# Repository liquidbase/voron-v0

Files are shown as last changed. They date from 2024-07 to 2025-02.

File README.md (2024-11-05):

# voron v0
Config repo for voron v0 to save the configuration and monitor changes made.

# Buildlog
26.07.2024
- Fixing Wiring
- Removed Display
- Removed BTT Pi1

27.07.2024
- Added Raspberry Pi 4B with MainsailOS
- 1st Startup
- Install updates for MainsailOS
- Upload first config
- Added main values for motors
- Added main vaules for thermistors
- Fixed macros
- Adjusted bed direction
- Adjusted StallGuard
- PID-Tuning für bed and nozzle

29.07.2024
- Added Display
- Added KlipperScreen

30.07.2024
- Added Shaketune
- Added Input Shaper LIS2DW
- Added frequencies
- Adjust frequencies

04.08.2024
- Disabled LIS2DW
- Layout Adjustments
- Configure Crowsnest
- Configure Neopixel

08.08.2024
- Added macro to control chamber led
- Better names

09.08.2024
- Adjust wait-time before print start
- Adjust value
- Added excluded_objects and adjusted run_current for X & Y
- Adjust Z-Endstop-Position
- Change invert on X & Y
- Added v0.2 CAD-File to .gitignore

13.08.2024
- Renamed comment
- Revert neopixel changes
- Adjusted neopixel color
- Adjusted position_endstop and max_temp

14.08.2024
- Enabled Line_Purge, Voron_Purge & Smart_Park
- Added KAMP for automatic Update

15.08.2024
- Changed chain_count for Neopixel
- Added better position after homing
- Added timelapse

14.09.2024
- Update temperatur for extruder and extrude distance
- Removed wait time and changed retract on print end

22.10.2024
- Moved Config folder to new folder Config_SKR-Pico
- Added config folder Config_Manta-M5P
- Added printer.cfg for Manta M5P after MCU change
- Removed uart_address

26.10.2024
- Added fan configuration
- Fixed neopixel pin

27.10.2024
- Added chamber thermistor

04.11.2024
- Fixed printer-section
- ReEnabled Sensorless homing

05.11.2024
- Added temperature sensors for mcu and host
- Added stepper config
- Fixed extruder

# Filelog
26.07.2024
- Added RPi_or_BTT-Pico_Mount.STL
- Added Images
- Added Image for MainsailOS to install
- Added display_mount.stl
- Added [a]_display_cover_hex_logo_x1.stl

27.07.2024
- Added rear_panel.3mf
- Added default printer.cfg for BTT SKR Pico

29.07.2024
- Added printfiles for handles
- Added new pictures
- Added KlipperScreen
- Added MFNano

30.07.2024
- Added ADXL Mount to printfiles

04.08.2024
- Removed MFNano
- Added Thermistormount in Chamber V0.2_NTC_10k_B3950_Mount.stl
- Added crowsnest.conf

06.08.2024
- Added waveshare-43-inch-display-mount-for-the-voron-v01-model_files

07.08.2024
- Added printfiles for LED-brackets, bottom hinge and Cam mount

14.08.2024
- Added moonraker.conf
- Added KAMP_Settings.cfg

15.08.2024
- Added diffuser print files
- Added print file for Front_Top_Right_Hinge_x1.stl

08.09.2024
- Added print files for Endstops

14.09.2024
- Added print files for 1515 end caps
- Added print files for Dragon Burner v8 with Orbiter v2
- Added print files for Dragon Burner v8 with Sherpa Mini

22.10.2024
- Added additional printfiles

26.10.2024
- Added printfiles for endstops

27.10.2024
- Added printfile for upper rear filament sensor

05.11.2024
- Added printfiles for foot corner
- Added printfiles for skirts

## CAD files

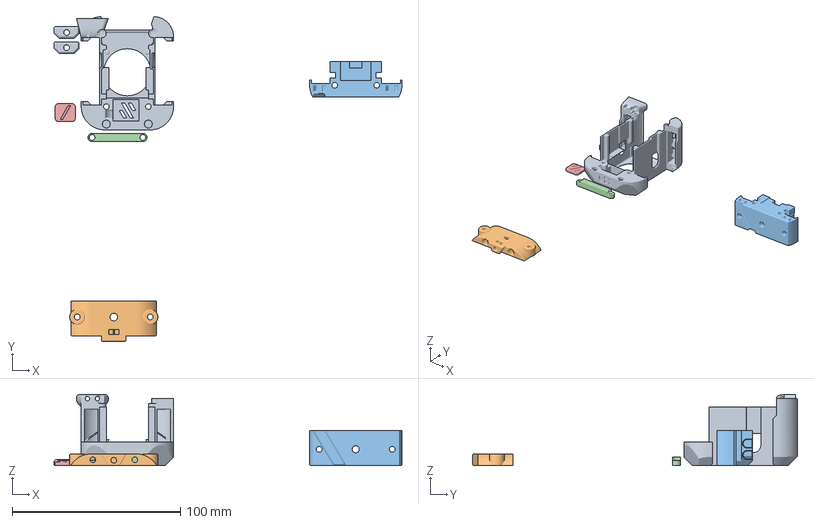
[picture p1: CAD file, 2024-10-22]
Printfiles/Dragon_Burner_v8_Sherpa_Mini/dragon_burner_v8.3mf
207.1 x 193.3 x 42.4 mm
Cowl_ZeroClick.stl
Sherpa_Mini_Mount.stl
Bambu_Mount.stl
Brace_Straight.stl
[c]_Voron_Diffuser.stl

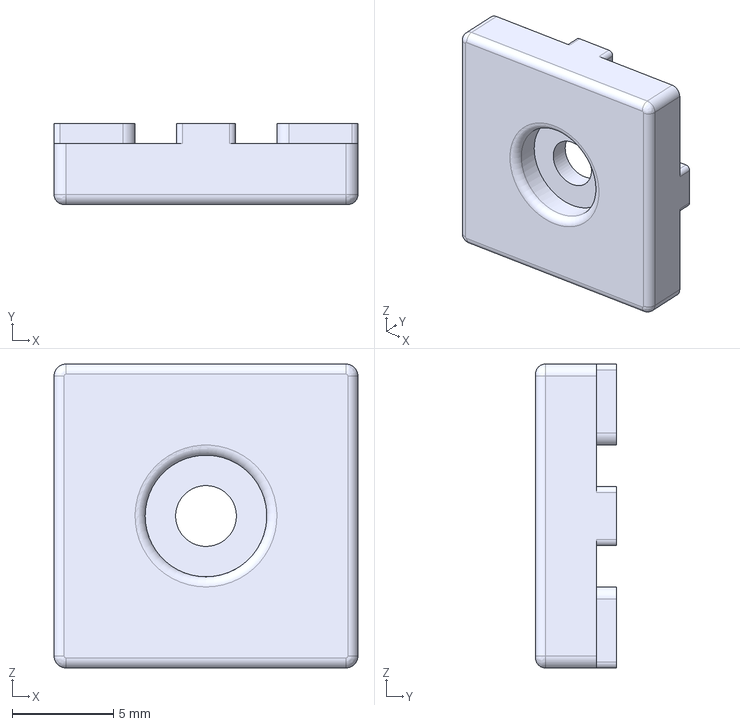
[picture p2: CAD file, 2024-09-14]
Printfiles/Endstop Case/1515 End Cap.step
15.0 x 4.00 x 15.0 mm

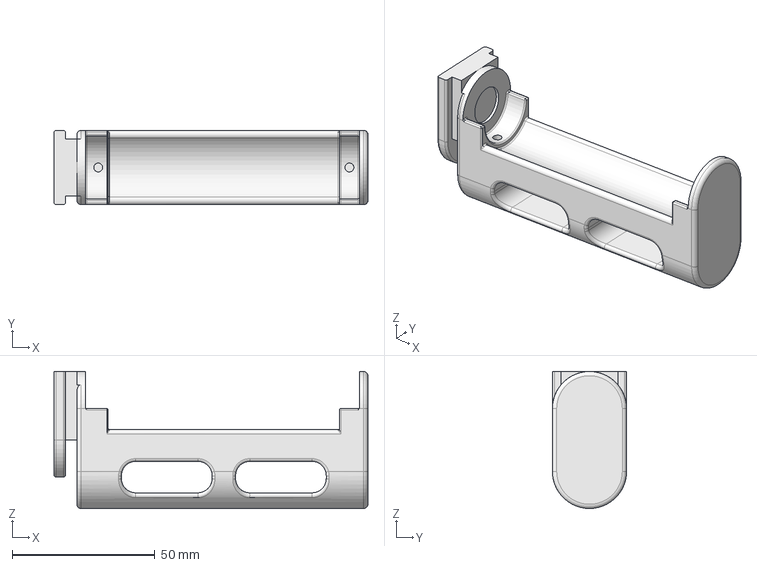
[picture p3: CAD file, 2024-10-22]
Printfiles/Filler 66mm Remix - 5335512/files/FillerBaseSource-66mm_mag.step
110.0 x 26.0 x 48.0 mm

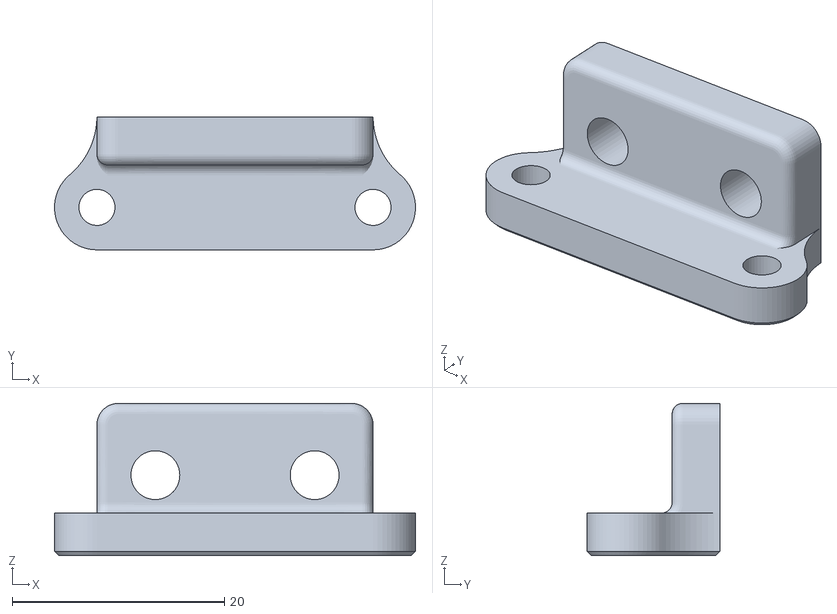
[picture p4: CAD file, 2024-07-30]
Printfiles/Mini Afterburner ADXL345 Mount by Andre/STL/MiniAB_ADXL345_Mount.stl
34.0 x 12.5 x 14.3

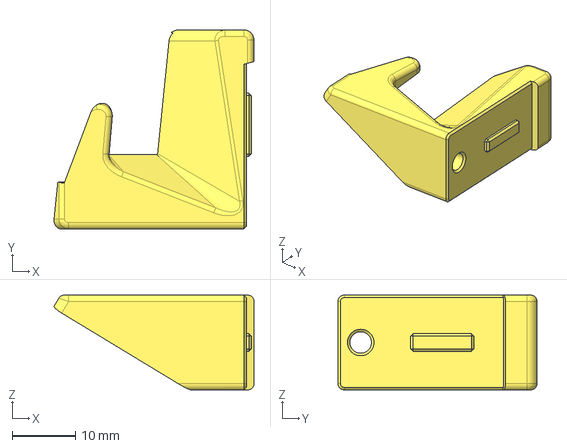
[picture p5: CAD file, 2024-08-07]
Printfiles/Raspberry Pi Camera Mount by johanncc/CAD/Raspberry_Pi_Camera_Mount.step
31.6 x 31.5 x 15.0 mm

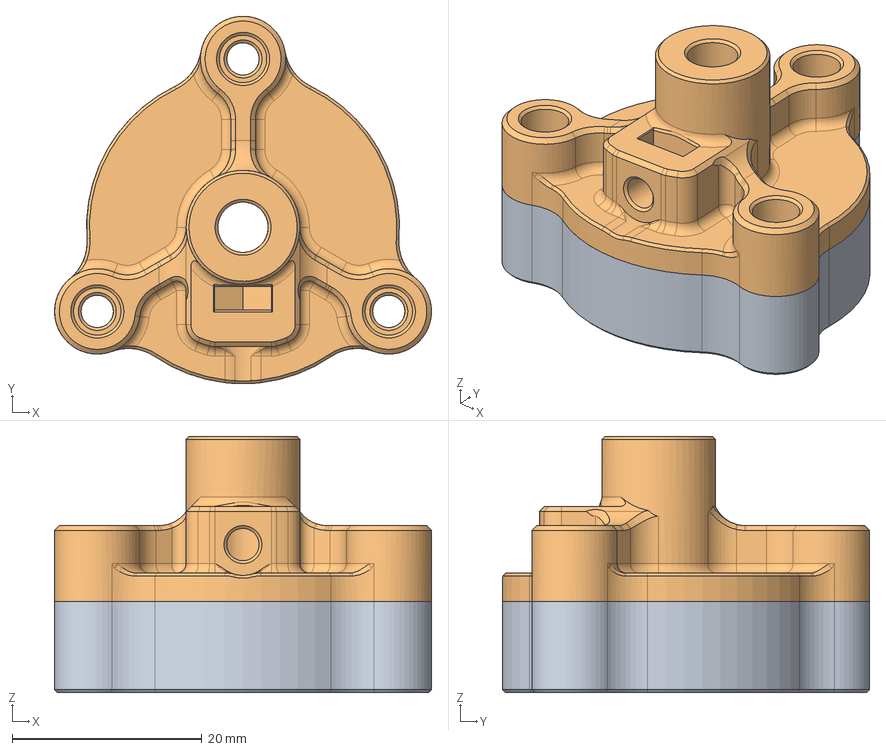
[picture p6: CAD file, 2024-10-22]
Printfiles/Sherpa_Mini-Extruder/Assembly_Tools/Shaft_Grinding_Tool/shaft_block v4.step
39.8 x 38.8 x 27.0 mm
bottom
top

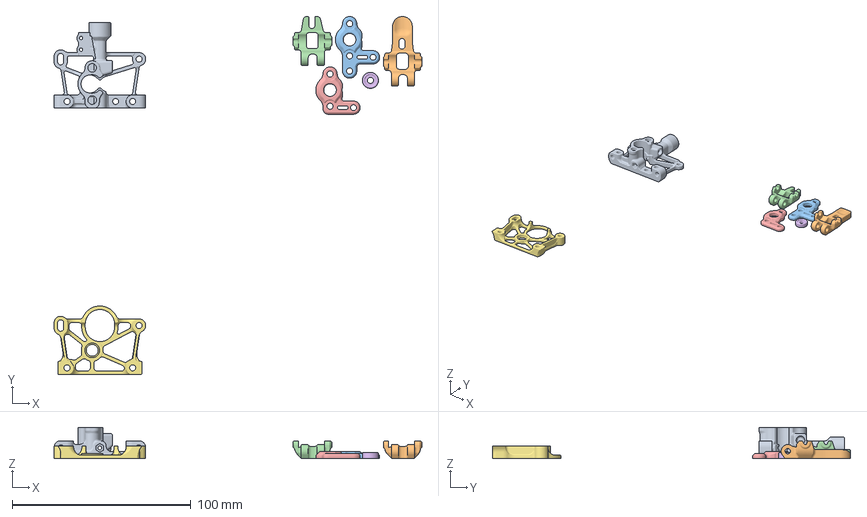
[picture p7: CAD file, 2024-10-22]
Printfiles/Sherpa_Mini-Extruder/housing_sherpa_mini_a3_r16(FDM)(FilamentSensor)(ECAS04).3mf
205.6 x 200.1 x 17.5 mm
housing_core_std^housing_sherpa_mini_a3_r16(FDM)(FilamentSensor)(ECAS04)
[a]_idler_arm_long_x1_rev16a.STL
[a]_housing_front_k_x1_rev15.STL
[a]_idler_arm_short_x1_rev16a.STL
[a]_housing_front_x1_rev15.STL
[a]_bondtech_thumbscrew_spacer_x1_rev1.STL
housing_rear_x1_rev17.STL

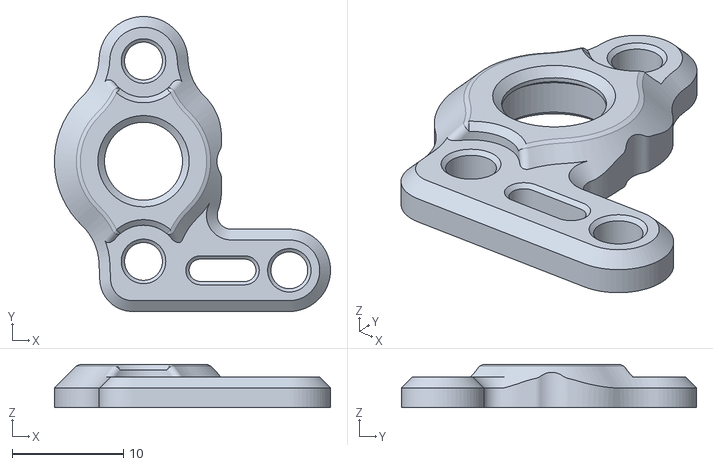
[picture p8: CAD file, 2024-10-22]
Printfiles/Sherpa_Mini-Extruder/STLs/[a]_housing_front_x1_rev15.STL
24.8 x 26.5 x 3.90

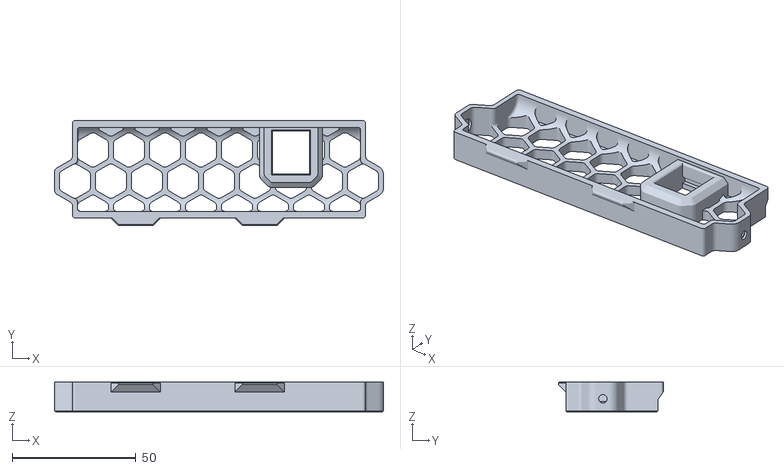
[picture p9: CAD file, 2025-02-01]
Printfiles/v0.2 Keystone Rear Skirt.stl
132.8 x 42.5 x 12.0

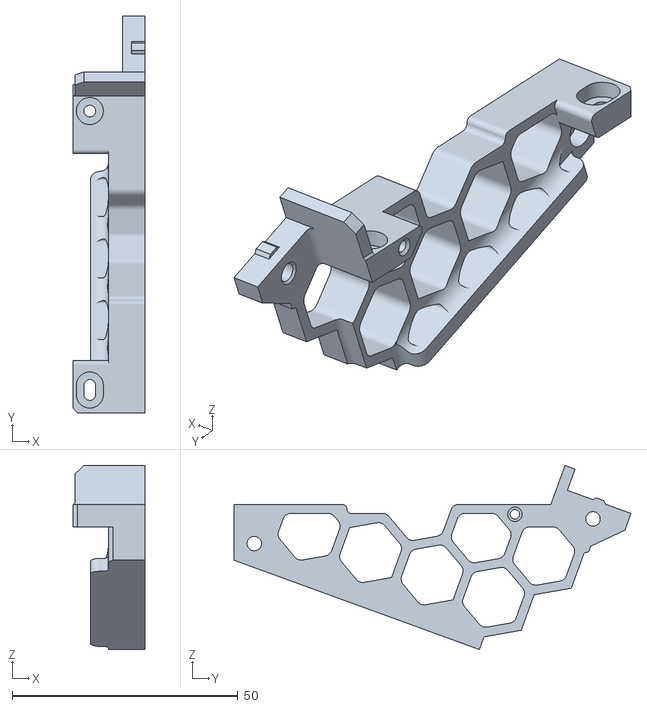
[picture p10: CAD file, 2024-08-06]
Printfiles/waveshare-43-inch-display-mount-for-the-voron-v01-model_files/mount_left.stl
15.9 x 88.0 x 40.8

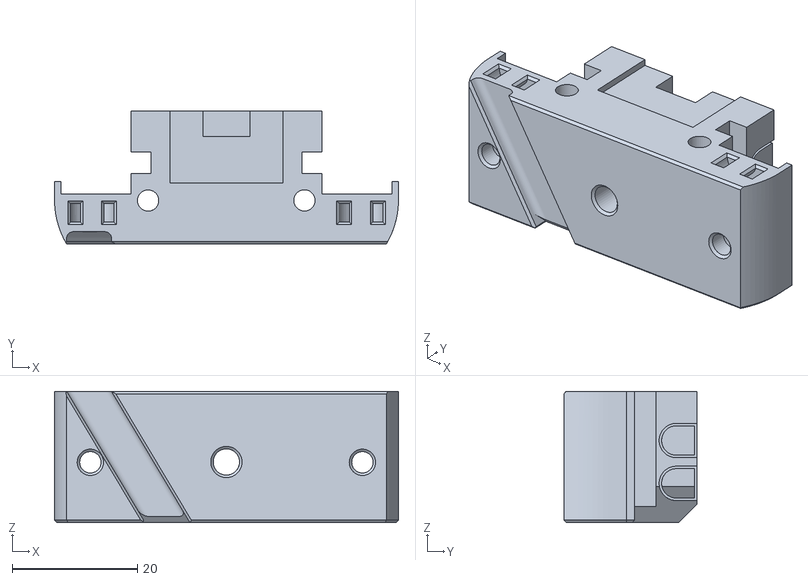
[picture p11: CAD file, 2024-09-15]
Printfiles/Dragon_Burner_v8_Sherpa_Mini/Bambu_Mount.stl
55.0 x 21.3 x 21.0

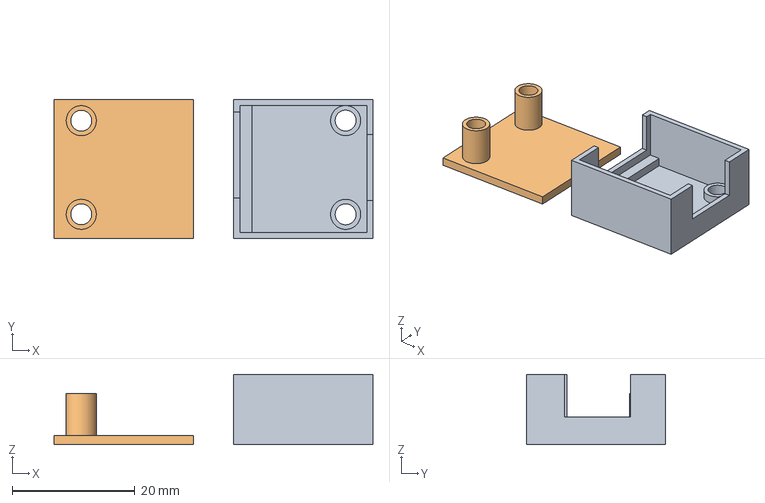
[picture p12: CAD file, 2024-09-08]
Printfiles/Endstop Case/Endstop Case v1.step
51.9 x 22.6 x 11.4 mm

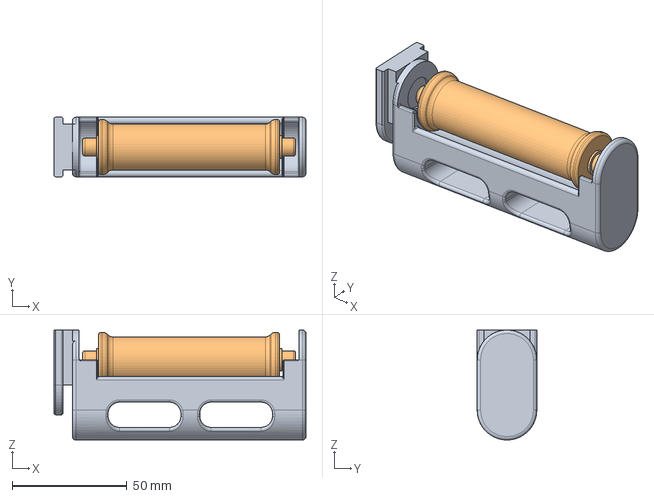
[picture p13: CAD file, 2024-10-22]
Printfiles/Filler 66mm Remix - 5335512/files/Filler-66mm.FCStd
110.0 x 26.0 x 48.0 mm
FillerBaseSource-66
FillerRollerSource-66

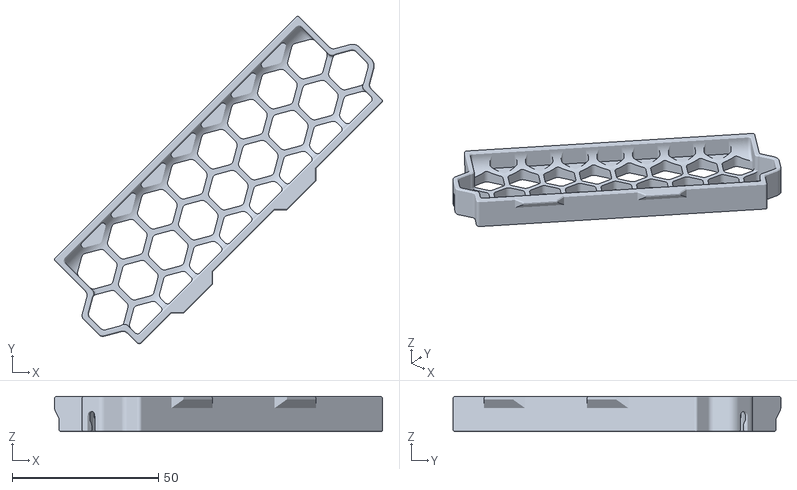
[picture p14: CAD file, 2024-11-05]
Printfiles/Rear_Skirt_x1.STL
112.3 x 112.1 x 12.0

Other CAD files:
Printfiles/Sherpa_Mini-Extruder/Assembly_Tools/Shaft_Grinding_Tool/bottom.stl
Printfiles/Sherpa_Mini-Extruder/STLs/housing_rear_x1_rev17.STL
Printfiles/Sherpa_Mini-Extruder/STLs/optional_parts/[a]_housing_front_k_x1_rev15.STL
Printfiles/1515 End Cap with Y Endstop for Voron V0.stl
Printfiles/1515_Hygrometer_mount.stl
Printfiles/Brackets_1515_x2.stl
Printfiles/Door_Latch_x2.STL
Printfiles/Dragon_Burner_v8_Sherpa_Mini/Brace_Straight.stl
Printfiles/Dragon_Burner_v8_Sherpa_Mini/Cowl_ZeroClick.stl
Printfiles/Dragon_Burner_v8_Sherpa_Mini/Sherpa_Mini_Mount.stl
Printfiles/Dragon_Burner_v8_Sherpa_Mini/[c]_Voron_Diffuser.stl
Printfiles/Endstop Case/1515 End Cap.stl
Printfiles/Endstop Case/1515 Endcap with Endstop Case v14.f3z
Printfiles/Endstop Case/1515 Endcap with Endstop Case v14.step
Printfiles/Endstop Case/1515 Endcap with Endstop Case v14.stl
Printfiles/Endstop Case/Endstop Case v1.f3d
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

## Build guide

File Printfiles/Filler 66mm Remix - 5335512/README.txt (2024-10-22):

Filler 66mm Remix by grzeegorzn on Thingiverse: https://www.thingiverse.com/thing:5335512

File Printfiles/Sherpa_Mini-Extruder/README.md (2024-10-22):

## Sherpa Mini - Release 2:

This release adds support for Bondtech's RIDGA v2 in addition to numerous tweaks and updates to make the extruder easier to work on and more reliable than ever. 

## Changelog

+ Bondtech RIDGA v2 compatibility (R2 RC1 and newer)
+ Bondtech insert support
+ Stronger and stiffer idler arm
+ Increased clearance between idler arm and core
+ Minor fixes and adjustments in preparation for upcoming upgrades

+ Core housing and rear housing need to be reprinted if upgrading from Release 1
+ Updated idler arms are backwards compatible with Release 1 and Release 2 RC1

## FAQ
For Material Requirements, Print Settings and How to Interpret the file naming structure, please see: "Print_Settings_and_File_Key.txt"

The BOM and Sourcing Guide for this product can be found here: https://docs.google.com/spreadsheets/d/1O3eyVuQ6M4F03MJSDs4Z71_XyNjXL5HFTZr1jsaAtRc/edit?usp=sharing

## Product Info
This is the Sherpa Mini Extruder, a ground up design developed by Anlin and the team at Annex Engineering. It's a dual geared hobbed filament extruder designed for use with any printer. It features a gear driven design to provide torque while being able to be near silent. You must perform your own tuning to get the best results.

A Pinion Equipped Pancake Stepper is required for this Release.

Our discord server can be found here: 

Join me on Discord (https://discord.gg/MzTR3zE)

Please only use GitHub Issues for repo and file related problems. For general design related questions and technical support please visit our Discord server.

Image of Sherpa Extruder

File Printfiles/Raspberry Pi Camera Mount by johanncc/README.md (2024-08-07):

# Voron 0/0.1 Raspberry Pi Camera Mount

This is a low profile raspberry pi camera mount for the Voron 0 / Voron 0.1.

**Please consider [downloading this model on Printables](https://www.printables.com/model/146877-voron-0-voron-01-raspberry-pi-camera-mount) as well to help me earn a roll of Prusament 😆**

## TLDR
1. Raspberry pi camera mount for the voron 0 / voron 0.1
2. Get up close and personal with the nozzle & the print bed (>80% visible)
3. Easy mounting with 1 M3x16 screw, 1 M3 nut and 1 M2x6 screws
4. **NO PRELOADING OF NUTS** thank goodness!
5. **No supports** as always!
5. Battle tested by users on Thingiverse and Printables!

## BOM
| Item | Qty. | Note |
| --- | --- | --- |
| M2x6 BHCS/SHCS | 1 - 2 | For securing the Raspberry Pi Camera |
| M3x16 BHCS | 1 | For securing to profile |
| M3 Nut | 1 | For securing to profile |
| **>300mm Flex Cable** | 1 | May be optional, see notes |

## Long Story
Ever since building my Voron 0.1, I've been trying to find a good mount for a raspberry pi camera. That said, most solutions I have found are a bit too conspicuous for my taste (i.e. they stick out into the tophat area), with no direct line of sight to the nozzle.

That's why I've decided to design my own and I've found a nice spot towards the top of the left z-extrusion with just enought clearance. It also offers good visibility of the nozzle & bed, extremely easy mounting, and great cable management!

Let me know what you think!

## Notes
- **The flex cable** that comes with the camera module will be too short for this mod if  your Raspberry Pi is located towards the bottom left of the electronics compartment (as per the manual). You can either purchase a 300mm / 12 in" flex cable or re-locate the Raspberry Pi towards the top of the compartment.
- **Clearnace** is quite tight (see one of the attached images), so I'd highly recommend that you check for inteference before commencing any prints. You can do so by moving the x-axis by hand along the back of the print bed. I'd also suggest that you check for any stray hotend wires so they don't snag on the camera
- **Material choice** is up to you, but if you're an enclosure (as I do), I'd highly recommend you print this model using ABS.
- **The focus distance** on the camera is usually set a too far out of the factory, resulting in a slightly blurry image. It is suggested that you adjust the focus ring on the camera to get a better image (not sure about warranty however).

## Images
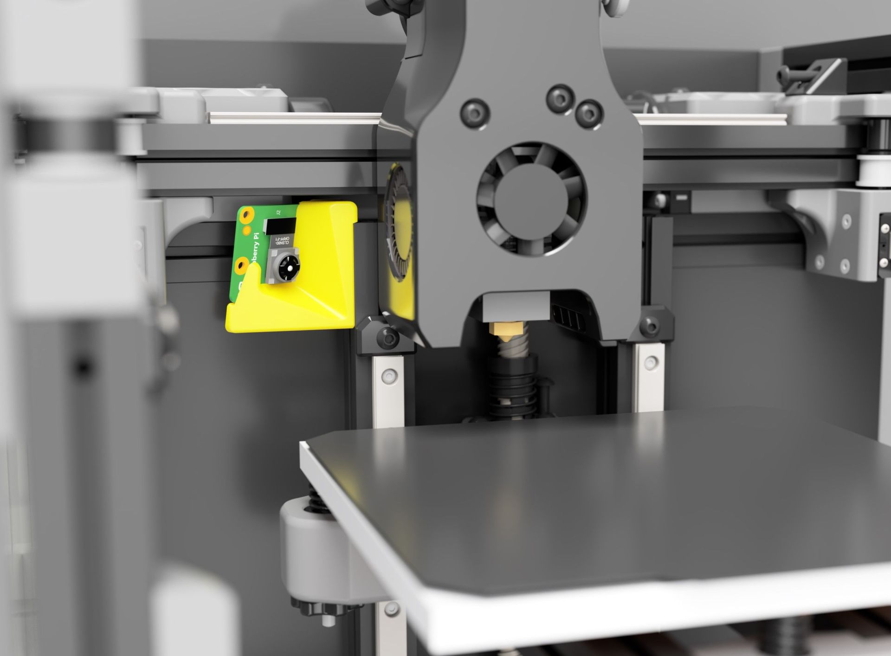
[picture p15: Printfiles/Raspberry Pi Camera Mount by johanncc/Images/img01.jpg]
0.1 Mount Image 01

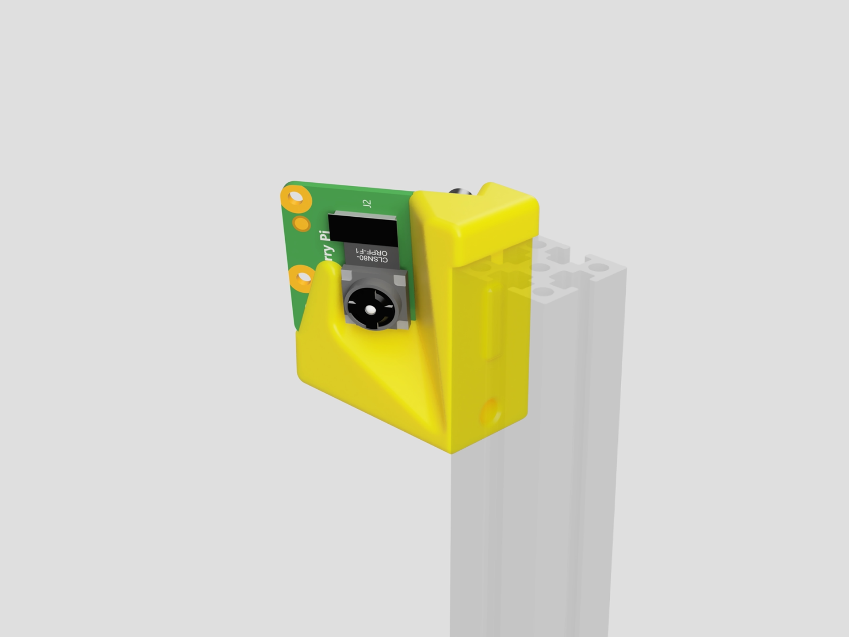
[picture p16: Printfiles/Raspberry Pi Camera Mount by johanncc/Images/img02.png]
0.1 Mount Image 02

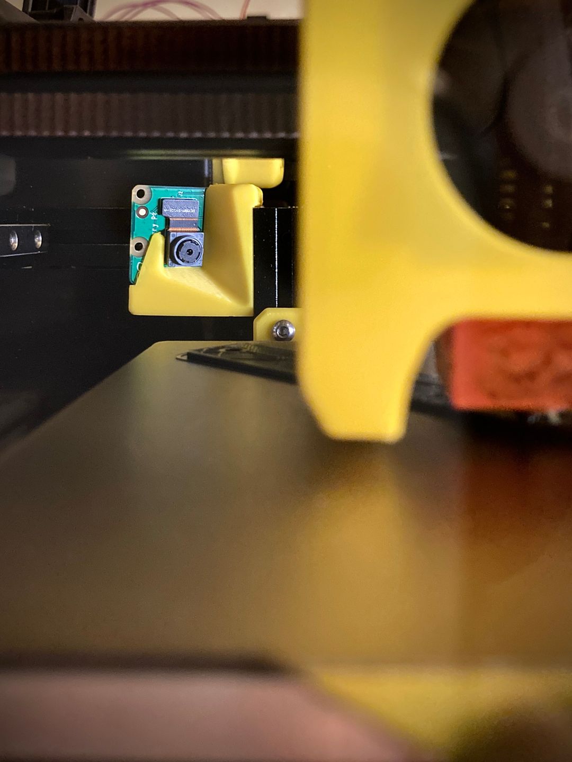
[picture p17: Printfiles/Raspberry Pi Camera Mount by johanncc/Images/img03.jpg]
0.1 Mount Image 03

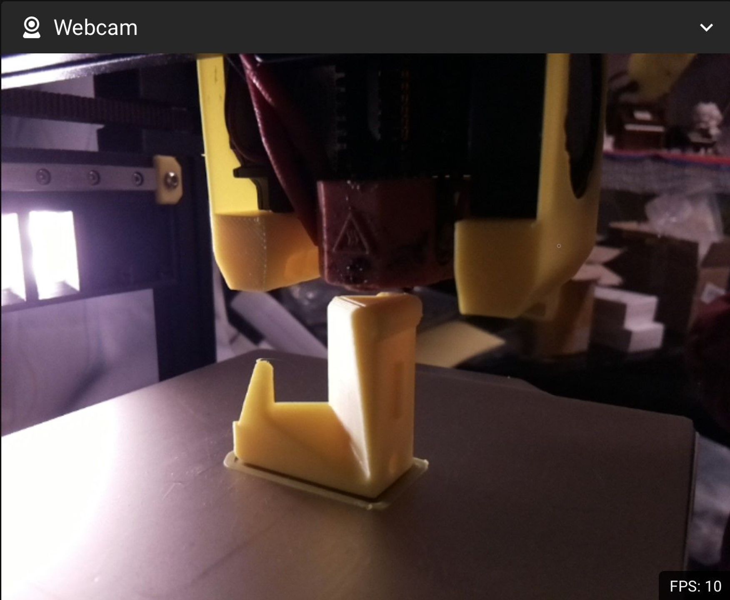
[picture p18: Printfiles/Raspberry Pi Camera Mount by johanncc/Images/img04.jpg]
0.1 Mount Image 04

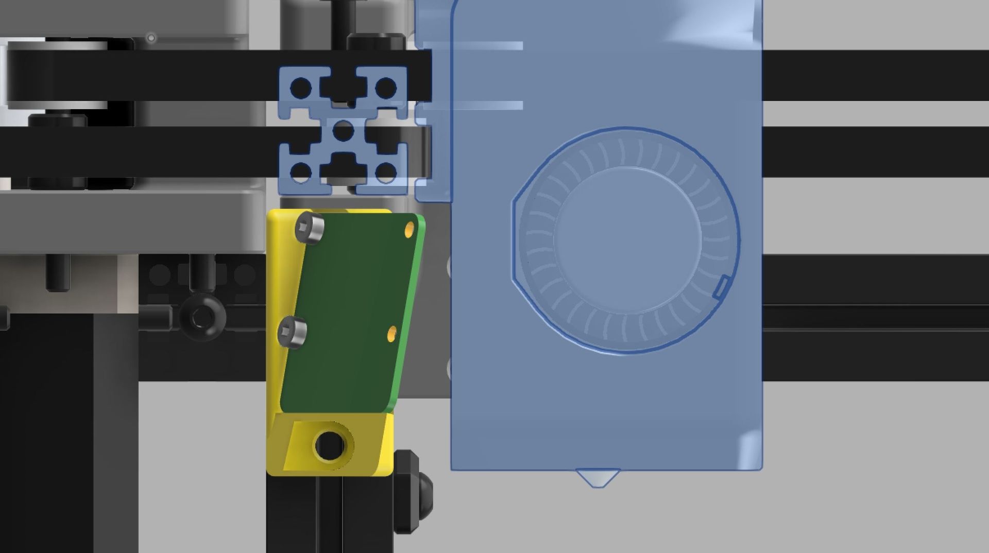
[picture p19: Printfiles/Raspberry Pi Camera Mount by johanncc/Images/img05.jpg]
0.1 Mount Image 05

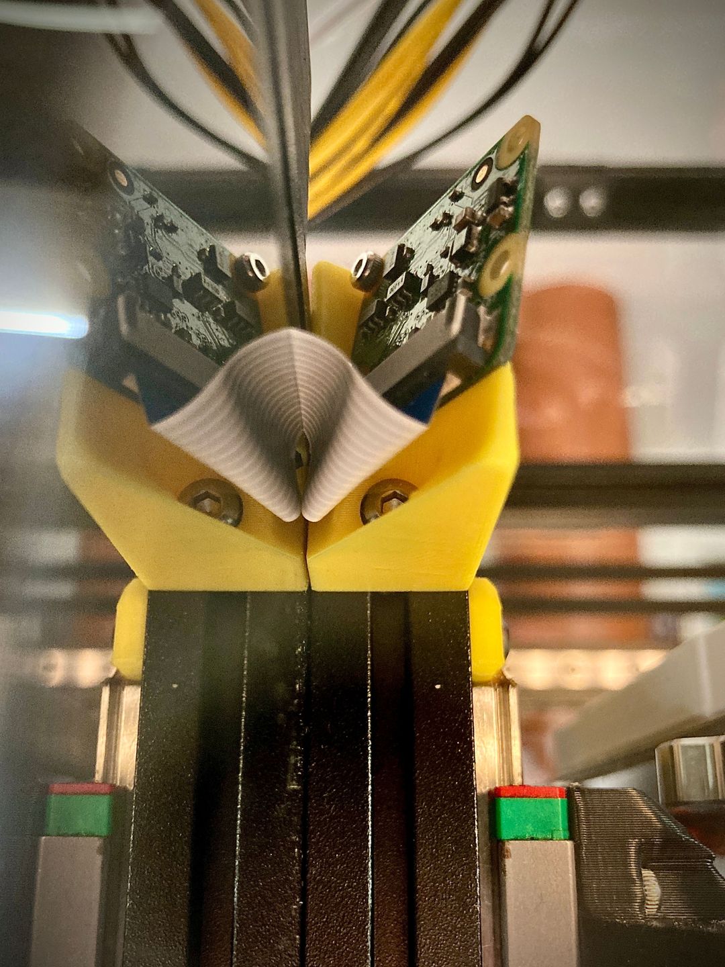
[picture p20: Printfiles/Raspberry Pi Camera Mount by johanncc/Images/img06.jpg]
0.1 Mount Image 06


*Raspberry pi camera model used in rendering designed by [Peter Höjerslev](https://grabcad.com/library/raspberry-pi-camera-4)*

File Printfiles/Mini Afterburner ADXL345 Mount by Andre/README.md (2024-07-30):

Mini Afterburner ADXL345 Mount
==============================

A mount to attach an ADXL345 sensor to the Mini-Afterburner toolhead.

BOM
---

- 2x M3x40 BHCS
- 2x M3 screws (at least 4mm, preferably nylon)
- 2x M3 heat-set insert. (3x5x4)

Instructions
------------

- Install the M3 heat-set inserts into the 2 larger holes on the part.  
- Remove the lowest 2 M3x35 screws from the front of the MiniAfterburner
- Attach the mount using 2 M3x40 screws in the same holes.
- attach the ADXL345 to the top of the mount, using m3 screws, ensure axes are oriented correctly.

Images
------

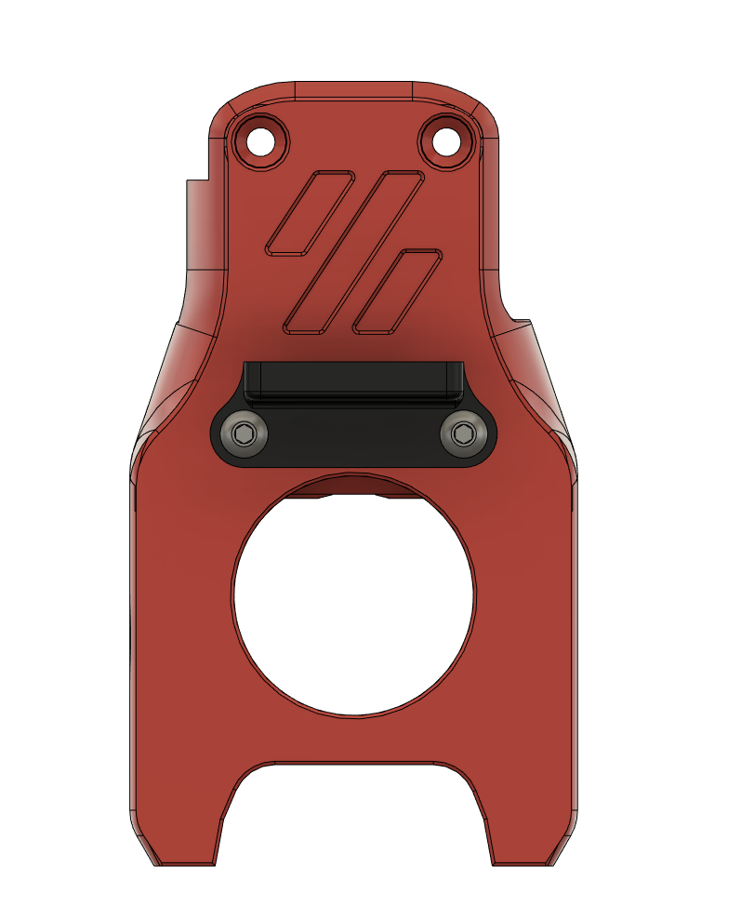
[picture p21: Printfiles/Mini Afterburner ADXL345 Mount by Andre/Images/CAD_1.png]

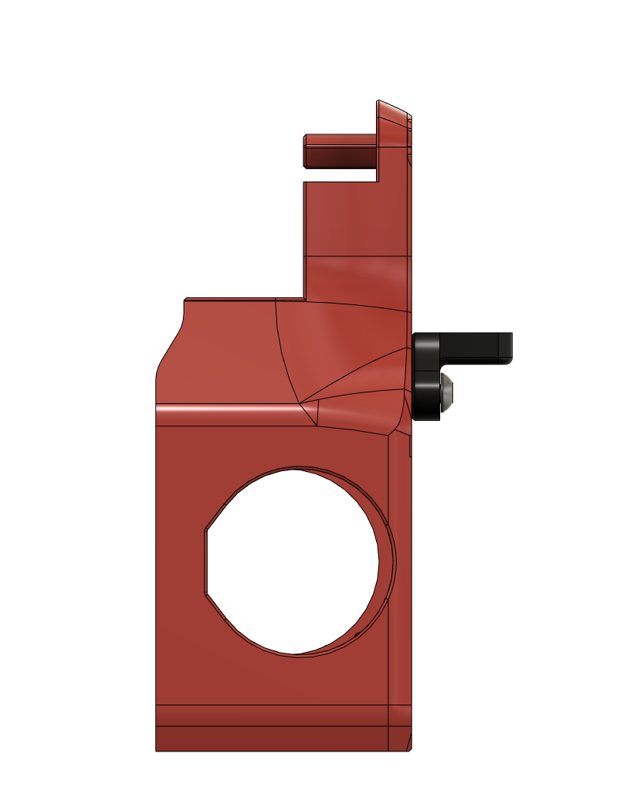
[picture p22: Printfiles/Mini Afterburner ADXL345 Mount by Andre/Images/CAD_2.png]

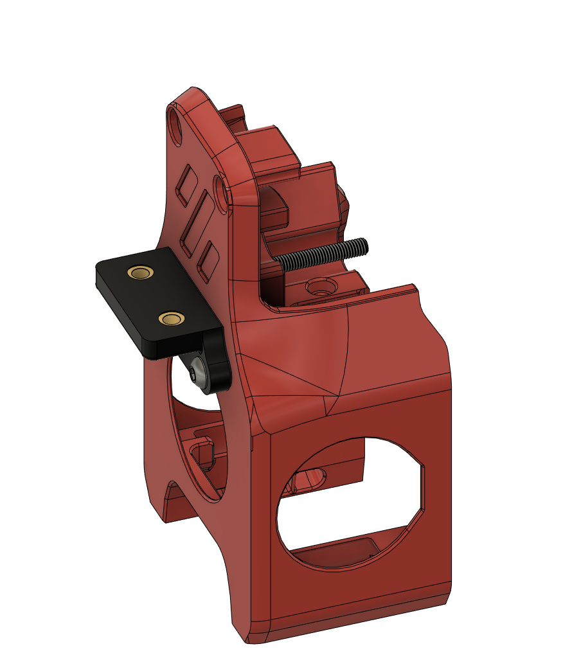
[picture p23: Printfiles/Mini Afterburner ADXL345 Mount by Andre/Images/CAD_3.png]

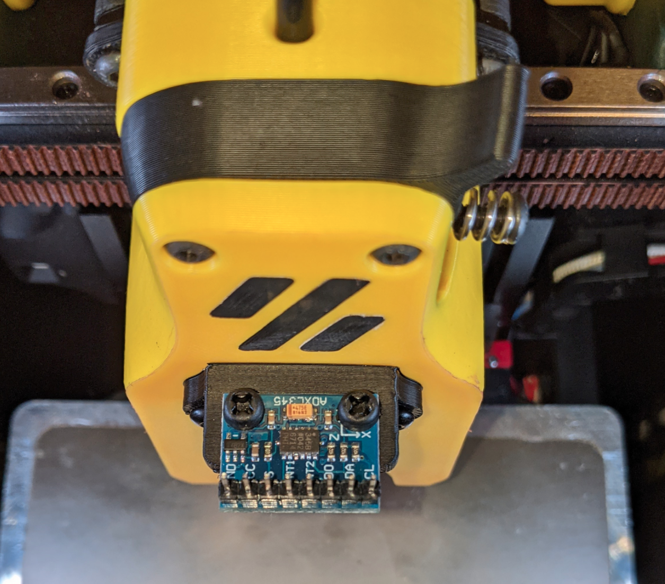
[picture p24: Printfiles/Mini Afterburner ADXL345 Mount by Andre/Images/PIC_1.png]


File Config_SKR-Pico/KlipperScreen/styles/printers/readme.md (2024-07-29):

In this folder add the images for the printer selection screen when using multiple printers

** No images will be provided from the main repo **

1. Supported formats: SVG (preferred) or PNG
2. The name of the image should be exactly equal to the printer name

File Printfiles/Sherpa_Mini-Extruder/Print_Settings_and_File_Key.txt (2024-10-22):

Primary Color: nothing at start of file name
Accent Color: [a]_ at start of file name
Quantity Required: _x# near end of file name
File Revision: _Rev# at end of file name

Nozzle Size: 0.4mm (RECOMMENDED)
Recommended FDM Materials: ASA (Fillamentum, Prusament, Polymaker or 3DXTech Recommended)
Alternate Approved FDM Materials: PC (3DXTech Recommended)
Layer Height: 0.10mm or 0.2mm
Extrusion Width: Forced 0.4mm
Infill Percentage: 40% minimum (at 0.6mm Width)
Infill Type: Grid, Gyroid, Honeycomb, Triangle or Cubic
Wall Count: 4 minimum (at 0.4mm Width)
Solid Top/Bottom Layers: 5 minimum (at 0.2mm Height)

Nozzle Size: 0.5mm 
Recommended FDM Materials: ASA (Fillamentum, Prusament, Polymaker or 3DXTech Recommended)
Alternate Approved FDM Materials: PC (3DXTech Recommended)
Layer Height: 0.1 or 0.2mm
Extrusion Width: Forced 0.5mm
Infill Percentage: 40% minimum (at 0.6mm Width)
Infill Type: Grid, Gyroid, Honeycomb, Triangle or Cubic
Wall Count: 4 minimum (at 0.5mm Width)
Solid Top/Bottom Layers: 5 minimum (at 0.2mm Height)

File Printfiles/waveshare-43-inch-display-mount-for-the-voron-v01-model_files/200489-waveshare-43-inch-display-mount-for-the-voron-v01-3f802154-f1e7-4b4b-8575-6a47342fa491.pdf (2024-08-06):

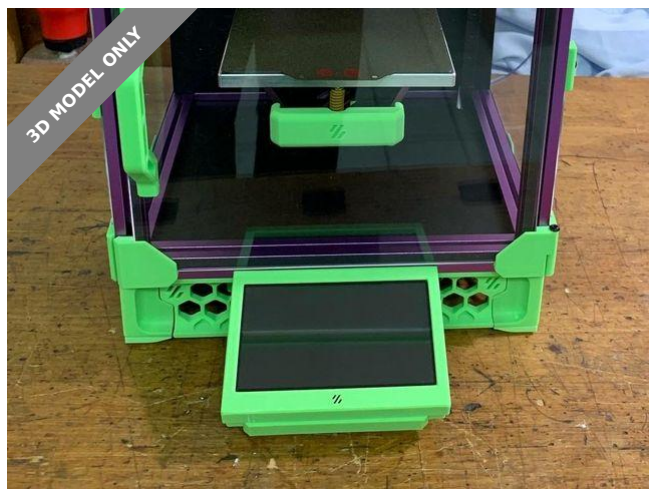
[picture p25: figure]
3D MODEL ONLY

## Summary

This display mount is intended for the VORON V0.1 in combination with the

V0.1 Trident Skirt mod.

3D Printers (https://www.printables.com/model?categoryId=1) | > | 3D Printers - Upgrades (https://www.printables.com/model?categoryId=2)
Tags: displaymount | vorondesign | voronmod | voron01

This Waveshave 4.3 inch displayholder is designed to fit perfectly onto the

VORON V0.1. The skirts i used were from the VORON Trident skirt mod for the VORON V0.1.

V0.1 Trident skirt mod:

https://github.com/Fleafa/VoronUsers/tree/V0.1-Trident-skirt/printer_mods/MCMBen/Voron0_Trident_Skirt (https://github.com/Fleafa/VoronUsers/tree/V0.1-Trident-skirt/printer_mods/MCMBen/Voron0_Trident_Skirt)

Used parts:

4x M3 threaded inserts

2x M2 threaded inserts

4x M3x10mm screws

2x M2x20mm screws
4x M2.5x6mm screws for mounting the display

2x M3x8mm screws for fixing the displayholder to the frame

Rettex31 (https://www.printables.com/social/128823/about)

## Waveshare 4.3 inch

## display mount for

# the VORON V0.1

VIEW IN BROWSER (https://www.printables.com/model/200489-waveshare-43-inch-display-mount-for-the-voron-v01)

updated 10. 5. 2022 | published 10. 5. 2022

•

•

•

•
•

•

printing the parts:

All the parts are printed in ASA or ABS with 4 outer perimeters and 40%

infill. Pay attention to orient the parts to be printable!

assembling the mount:

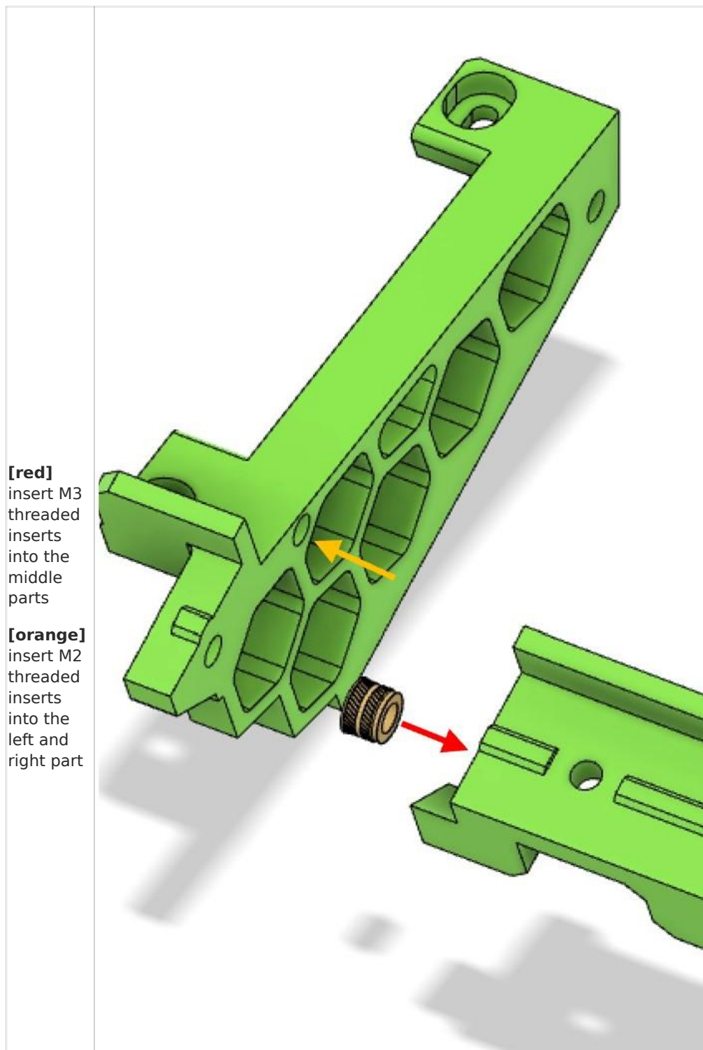
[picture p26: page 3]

## [red]

insert M3

threaded

inserts

into the

### middle

parts

[orange]

insert M2

threaded

inserts

into the

### left and

right part

## [red]

Complete
the

assembly
by

screwing

### in the

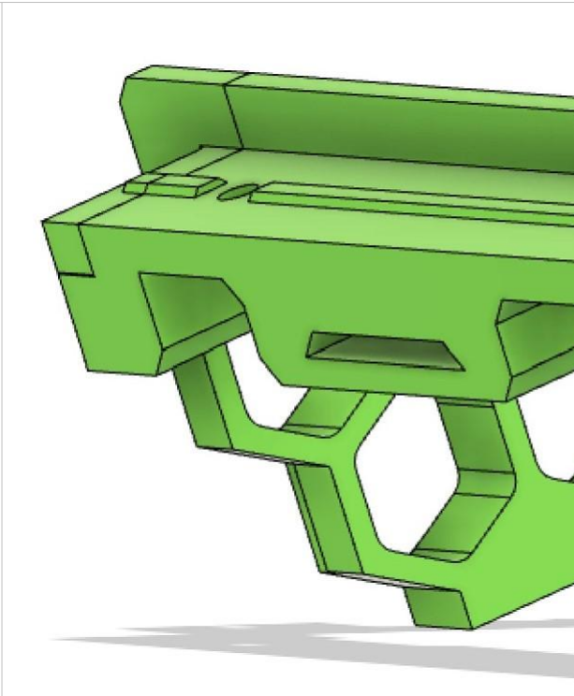
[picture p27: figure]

M3x10mm

screws.

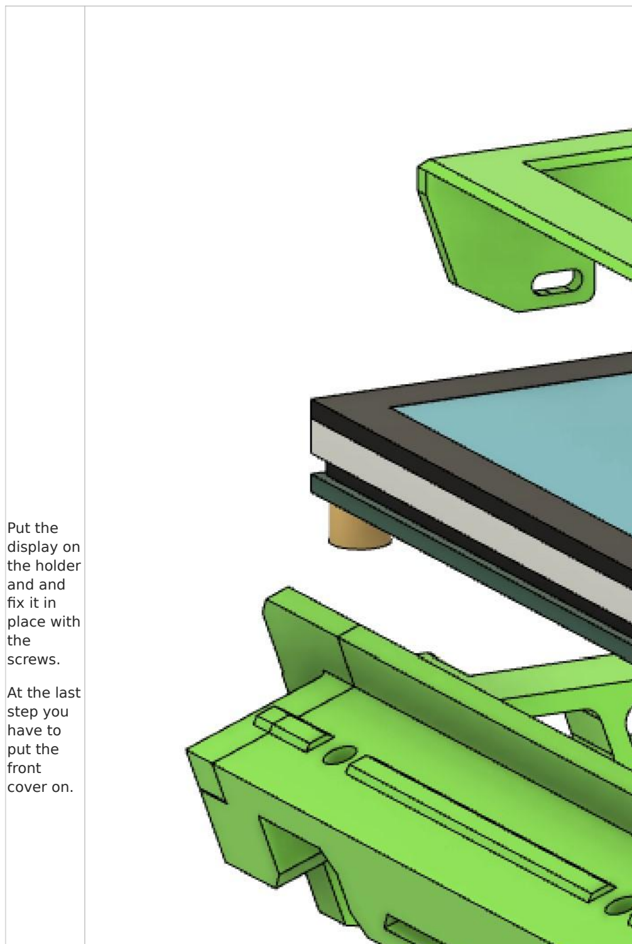
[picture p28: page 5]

Put the

display on

### the holder

and and

### fix it in

place with
the

screws.

At the last

step you
have to
put the

front

cover on.

# Model files

If there are any questions left you can contact me. Happy printing and

## building!

## License

This work is licensed under a

Creative Commons (4.0 International License)

Attribution—Noncommercial—Share Alike (http://creativecommons.org/licenses/by-nc-sa/4.0/)

✖ | Sharing without ATTRIBUTION
✔ | Remix Culture allowed
✖ | Commercial Use

cover_front.stl

mount_rear.stl

mount_front.stl

mount_right.stl

mount_left.stl

✖ | Free Cultural Works
✖ | Meets Open Definition

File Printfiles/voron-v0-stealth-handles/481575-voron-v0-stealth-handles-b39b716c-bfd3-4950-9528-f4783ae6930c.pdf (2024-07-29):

## Voron V0 Stealth Handles

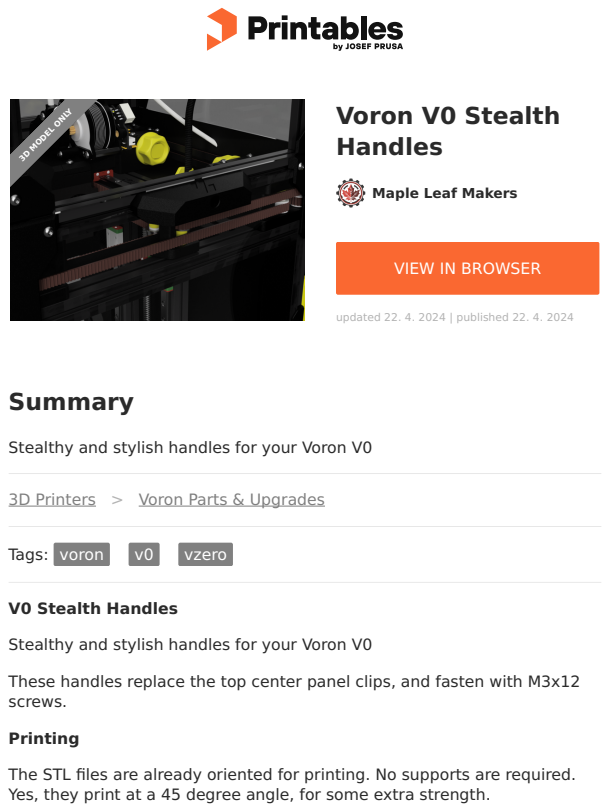
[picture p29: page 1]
Summary; Tags:; voron; vzero; V0 Stealth Handles; Printing; updated 22. 4. 2024 | published 22. 4. 2024; 3D MODEL ONLY

Maple Leaf Makers (https://printables.com/@MapleLeafMakers)

VIEW IN BROWSER (https://printables.com/model/481575-voron-v0-stealth-handles)

Stealthy and stylish handles for your Voron V0

3D Printers (https://printables.com/model?categoryId=1) > Voron Parts & Upgrades (https://printables.com/model?categoryId=137)

These handles replace the top center panel clips, and fasten with M3x12
screws.

The STL files are already oriented for printing. No supports are required.
Yes, they print at a 45 degree angle, for some extra strength.

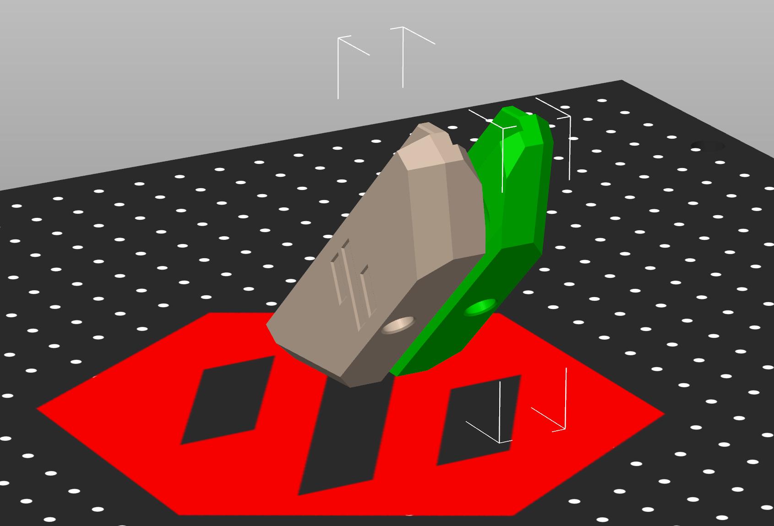
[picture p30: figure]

## Model files

## License

This work is licensed under a GNU (https://www.gnu.org/licenses/gpl-3.0.html)

stealth_handle.step

handle_a.stl

handle_b.stl

General Public License v3.0 (https://www.gnu.org/licenses/gpl-3.0.html)

✖ | Sharing without ATTRIBUTION
✔ | Remix Culture allowed
✔ | Commercial Use
✔ | Meets Open Definition
ℹ | Share under the same license

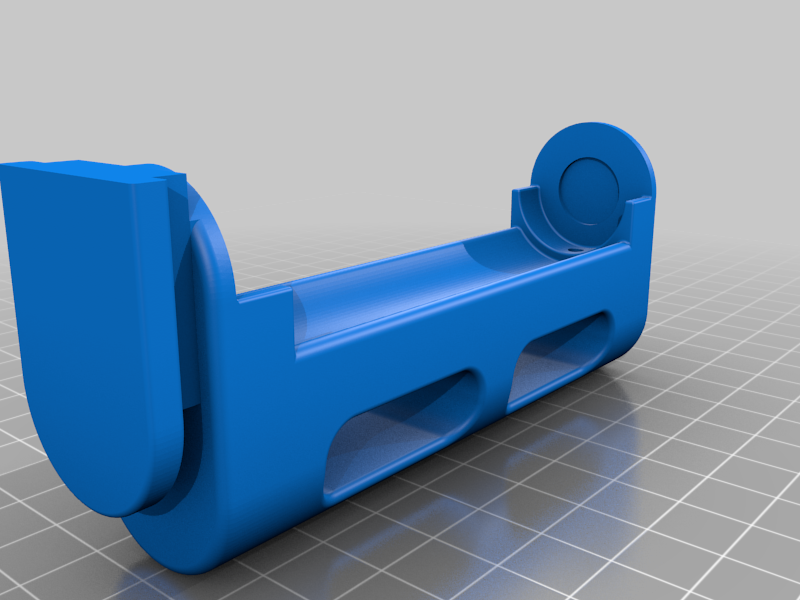
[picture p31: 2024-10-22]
Printfiles/Filler 66mm Remix - 5335512/images/FillerBaseSource-66mm_mag.png

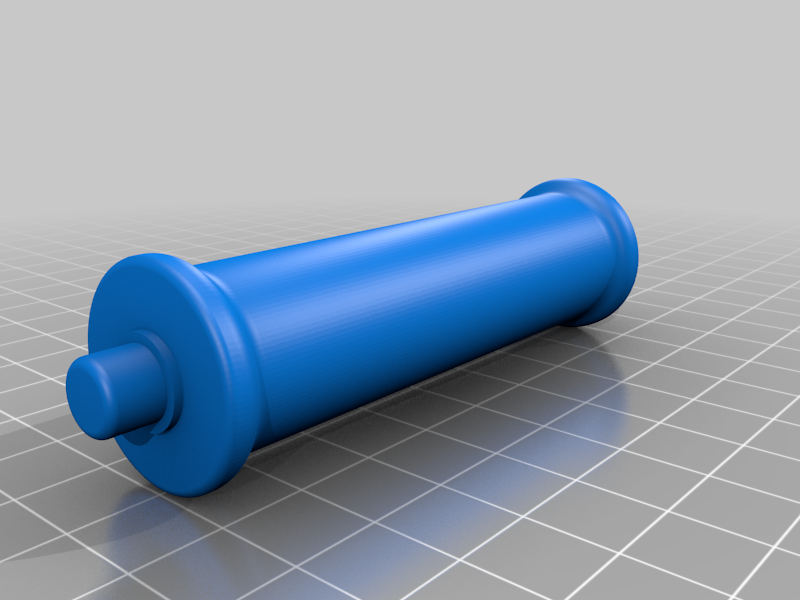
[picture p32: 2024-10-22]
Printfiles/Filler 66mm Remix - 5335512/images/FillerRollerSource-66mm.png

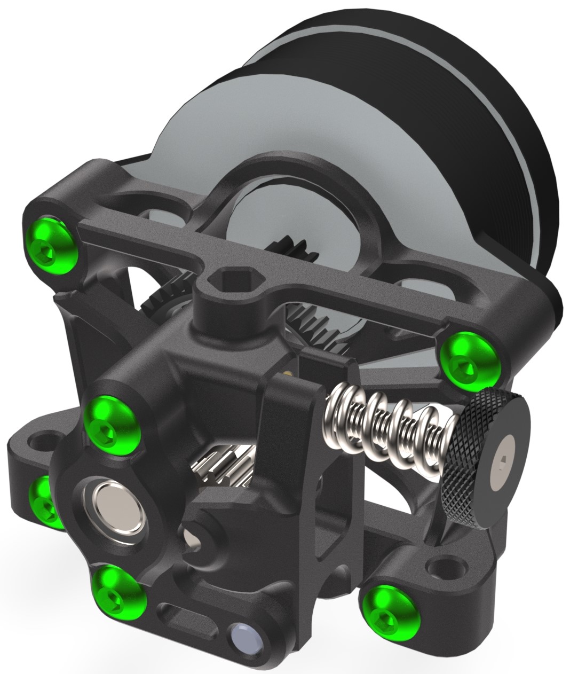
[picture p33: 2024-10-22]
Printfiles/Sherpa_Mini-Extruder/Images/sherpa_mini_rc1.jpg

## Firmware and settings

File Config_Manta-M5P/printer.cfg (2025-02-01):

[include mainsail.cfg]

#########################
# MCU
#########################

[mcu]
serial: /dev/serial/by-id/usb-Klipper_stm32g0b1xx_29003E001950425938323120-if00
restart_method: command

[temperature_sensor mcu_temp]
sensor_type: temperature_mcu
min_temp: 0
max_temp: 100

[temperature_sensor host_temp]
sensor_type: temperature_host
min_temp: 10
max_temp: 100

#########################
# Input Shaping
#########################

#[adxl345]
#cs_pin: PC0
#spi_bus: spi2

#########################
# Printer
#########################

[printer]
kinematics: corexy
max_velocity: 500
max_accel: 400
max_z_velocity: 15
max_z_accel: 300
square_corner_velocity: 6.0

#########################
# X/Y Stepper
#
# Motor A (r) = Y = M2
# Motor B (l) = X = M1
#########################

[stepper_x]
step_pin: PC8
dir_pin: PC9
enable_pin: !PA15
microsteps: 32
rotation_distance: 40
full_steps_per_rotation: 200
endstop_pin: tmc2209_stepper_x:virtual_endstop
position_endstop: 120
position_max: 120 
homing_speed: 50
homing_retract_dist: 0
homing_positive_dir: true

[tmc2209 stepper_x]
uart_pin: PD9
run_current: 0.800
interpolate: True
sense_resistor: 0.110
stealthchop_threshold: 0                                            # Set to 999999 to turn stealthchop on, and 0 to use spreadcycle
diag_pin: ^PD3
driver_SGTHRS: 75

[stepper_y]
step_pin: PA10
dir_pin: PA14
enable_pin: !PA13
microsteps: 32
rotation_distance: 40
full_steps_per_rotation: 200
endstop_pin: tmc2209_stepper_y:virtual_endstop
position_endstop: 119
position_max: 119
homing_speed: 50
homing_retract_dist: 0
homing_positive_dir: true

[tmc2209 stepper_y]
uart_pin: PD8
run_current: 0.800
interpolate: True
sense_resistor: 0.110
stealthchop_threshold: 0                                            # Set to 999999 to turn stealthchop on, and 0 to use spreadcycle
diag_pin: ^PD2
driver_SGTHRS: 75

#########################
# Z Stepper Settings
#
# Motor C (b) = Z = M3
#########################

[stepper_z]
step_pin: PC6
dir_pin: !PC7
enable_pin: !PA9
microsteps: 32
rotation_distance: 8
endstop_pin: PC3
position_max: 120
position_min: -1.5
#position_endstop: 119.800
homing_speed: 50
second_homing_speed: 3.0
homing_retract_dist: 3.0

[tmc2209 stepper_z]
uart_pin: PB10
diag_pin: PC3
interpolate: False
## Moons LE174S-T0808-200-0-S-965
run_current: 0.30
sense_resistor: 0.110
stealthchop_threshold: 0 

#########################
# Extruder
#########################

[extruder]
step_pin: PB12
dir_pin: PB11
enable_pin: !PA8
microsteps: 16
full_steps_per_rotation: 200
rotation_distance: 4.637
nozzle_diameter: 0.400
filament_diameter: 1.750
heater_pin: PC5
sensor_type: PT1000
sensor_pin: PA1
#control: pid
#pid_Kp: 21.527
#pid_Ki: 1.063
#pid_Kd: 108.982
min_temp: 0
max_temp: 355
min_extrude_temp: 170
max_extrude_only_distance: 150
max_extrude_cross_section: 0.8
pressure_advance: 0.0                                               # See tuning pressure advance doc
pressure_advance_smooth_time: 0.040

[tmc2209 extruder]
uart_pin: PB2
interpolate: True
run_current: 0.6
diag_pin: ^PC2
sense_resistor: 0.110
stealthchop_threshold: 0

#########################
# Filament Runout Sensor
#########################

[filament_switch_sensor filament_runout]
switch_pin: !PC2
pause_on_runout: True
runout_gcode: PAUSE

#########################
# Heat Bed
#########################

[heater_bed]
heater_pin: PA5
sensor_type: Generic 3950
sensor_pin: PA0
control: watermark
min_temp: 0
max_temp: 130

#########################
# Fan Control
#########################

[heater_fan Hotend]
pin: PA4
max_power: 1.0
kick_start_time: 0.5
heater: extruder
heater_temp: 50.0

[fan]
pin: PA3
max_power: 1.0
kick_start_time: 0.5
off_below: 0.13
cycle_time: 0.010

#########################
# Temperature Sensor
#########################

[thermistor NTC10K]
temperature1: 0.0
resistance1: 32116.0
temperature2: 40.0
resistance2: 5309.0
temperature3: 80.0
resistance3: 1228.0

[temperature_sensor chamber]
sensor_type: NTC10K
sensor_pin: PA2
min_temp: 0
max_temp: 100

#########################
# Additional Headers
#########################

[board_pins]
aliases:
    # EXP1 header
    EXP1_1=PD5, EXP1_3=PB3, EXP1_5=PB5, EXP1_7=PB7, EXP1_9=<GND>,
    EXP1_2=PD4,  EXP1_4=PD6, EXP1_6=PB4, EXP1_8=PB6, EXP1_10=<5V>,
    # EXP2 header
    EXP2_1=PB14, EXP2_3=PB8, EXP2_5=PC10, EXP2_7=PC12,  EXP2_9=<GND>,
    EXP2_2=PB13, EXP2_4=PB9, EXP2_6=PB15, EXP2_8=<RST>, EXP2_10=<NC>

#########################
# Neopixel
#########################

[neopixel chamber_led]
pin: PC14
chain_count: 20
color_order: GRB
initial_RED: 1
initial_GREEN: 1
initial_BLUE: 1

#########################
# Homing and Gantry
# Adjustment Routines
#########################

[idle_timeout]
timeout: 1800

[homing_override]
axes: xyz
set_position_z: 0
gcode:
  {% set home_all = 'X' not in params and 'Y' not in params and 'Z' not in params %}
  SAVE_GCODE_STATE NAME=STATE_HOME_OVERRIDE

  {% if home_all or 'Z' in params %}
    HOME_Z
  {% endif %}

  {% if home_all or 'X' in params %}
    HOME_X
  {% endif %}
  
  {% if home_all or 'Y' in params %}
    HOME_Y
  {% endif %}
  G1 X60 Y60 Z30

#[safe_z_home]
##home_xy_position: 120,120 										# these coordinates must NOT be greater than the values specified in "position_max:" for the X and Y steppers
#speed: 50.0
#z_hop: 5

## To be used with BED_SCREWS_ADJUST
[bed_screws]
screw1: 60,5
screw1_name: front screw
screw2: 5,115
screw2_name: back left
screw3: 115,115
screw3_name: back right

#########################
# Exclude objects
# during print
#########################
[exclude_object]

#########################
# Macros
#########################

# print_start macro
[gcode_macro PRINT_START]
gcode:
  G92 E0
  # This part fetches data from your slicer. Such as bed temp, extruder temp, chamber temp and size of your printer.
  {% set target_bed = params.BED|int %}
  {% set target_extruder = params.EXTRUDER|int %}
  #{% set target_chamber = params.CHAMBER|default("40")|int %}
  {% set x_wait = printer.toolhead.axis_maximum.x|float / 2 %}
  {% set y_wait = printer.toolhead.axis_maximum.y|float / 2 %}

  # Homes the printer and sets absolute positioning
  G28                   # Full home (XYZ)
  G90                   # Absolut position

  # Checks if the bed temp is higher than 90c - if so then trigger a heatsoak
  {% if params.BED|int > 90 %}
    M106 S255                                         # Turns on the PT-fan

    G1 X{x_wait} Y{y_wait} Z15 F9000                  # Goes to center of the bed
    M190 S{target_bed}                                # Sets target temp for the bed
    #TEMPERATURE_WAIT SENSOR="temperature_sensor chamber" MINIMUM={target_chamber}   # Waits for chamber to reach desired temp
  {% endif %}

  # Heats up the nozzle up to target via slicer
  M107                                              # Turns off the PT-fan
  M109 S{target_extruder}                           # Heats the nozzle to your print temp

  # Create a purge line and starts the print
  G1 X5 Y4 Z0.4 F10000                             # Moves to starting point
  G1 X115 E20 F1000                                # Purge line
   
[gcode_macro PRINT_END]
#   Use PRINT_END for the slicer ending script - please customize for your slicer of choice
gcode:
    M400                           ; wait for buffer to clear
    G92 E0                         ; zero the extruder
    G1 E-10.0 F3600                ; retract filament
    G91                            ; relative positioning

    #   Get Boundaries
    {% set max_x = printer.configfile.config["stepper_x"]["position_max"]|float %}
    {% set max_y = printer.configfile.config["stepper_y"]["position_max"]|float %}
    {% set max_z = printer.configfile.config["stepper_z"]["position_max"]|float %}

    #   Check end position to determine safe direction to move
    {% if printer.toolhead.position.x < (max_x - 20) %}
        {% set x_safe = 20.0 %}
    {% else %}
        {% set x_safe = -20.0 %}
    {% endif %}

    {% if printer.toolhead.position.y < (max_y - 20) %}
        {% set y_safe = 20.0 %}
    {% else %}
        {% set y_safe = -20.0 %}
    {% endif %}

    {% if printer.toolhead.position.z < (max_z - 15) %}
        {% set z_safe = 15.0 %}
    {% else %}
        {% set z_safe = max_z - printer.toolhead.position.z %}
    {% endif %}

    G0 Z{z_safe} F3600             ; move nozzle up
    G0 X{x_safe} Y{y_safe} F20000  ; move nozzle to remove stringing
    TURN_OFF_HEATERS
    M107                           ; turn off fan
    G90                            ; absolute positioning
    G0 X60 Y{max_y-10} F3600          ; park nozzle at rear
  
[gcode_macro LOAD_FILAMENT]
gcode:
   M83                            ; set extruder to relative
   G1 E30 F300                    ; load
   G1 E15 F150                    ; prime nozzle with filament
   M82                            ; set extruder to absolute
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

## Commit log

2024-07-26 Fixing and prepartion
    [RPi_or_BTT-Pico_Mount.STL]
2024-07-26 Added printfiles for display
    [[a]_display_cover_hex_logo_x1.stl, display_mount.stl]
2024-07-27 Added open rear panel
    [rear_panel.3mf]
2024-07-27 Default printer.cfg
    [printer.cfg]
2024-07-27 Added MCU-Path, uncomment Runout-Sensor
    [printer.cfg]
2024-07-27 Added run_current for motors
    [printer.cfg]
2024-07-27 Fixed run_current for Z and extruder
    [printer.cfg]
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2024-07-27 Added thermistors and heat wattage
    [printer.cfg]
2024-07-27 Enabled Homing
    [printer.cfg]
2024-07-27 Fixed toolhead macro
    [printer.cfg]
2024-07-27 Adjusted home macros
    [printer.cfg]
2024-07-27 Adjust homing_speed
    [printer.cfg]
2024-07-27 Fixed position_max for Y
    [printer.cfg]
2024-07-27 PID-Tuning via klipper done
    [printer.cfg]
2024-07-27 Adjust config
    [printer.cfg]
2024-07-27 Adjust StallGuard
    [printer.cfg]
2024-07-27 Fixed directions
    [printer.cfg]
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2024-07-28 Adjusted print_start macro
    [printer.cfg]
2024-07-28 Removed unnecessarily parts
    [printer.cfg]
2024-07-28 Disabled target_chamber
    [printer.cfg]
2024-07-28 Added voron cube
    [Voron_Design_Cube_v7.stl]
2024-07-28 Adjusted print_stop macro
    [printer.cfg]
2024-07-29 Added printfiles for handles
    [handle_a.stl, handle_b.stl, stealth_handle.step]
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2024-07-29 Added MFNano to printfiles
    [cartridge_body.stl, cartridge_lid.stl, magclip_x2.stl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]
2024-07-30 Added ADXL Mount to printfiles
    [MFNano.3mf, MiniAB_ADXL345_Mount.stl, MiniAB_ADXL_Mount.f3d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]
2024-07-30 Added Input Shaper LIS2DW
    [printer.cfg]
2024-07-30 Adjust probe_points
    [printer.cfg]
2024-07-30 Added Shaketune
    [printer.cfg]
2024-07-30 Added frequencies
    [printer.cfg]
2024-07-30 Adjust frequencys
    [printer.cfg]
2024-08-04 Disabled LIS2DW
    [printer.cfg]
2024-08-04 Removed MFNano
    [MFNano.3mf, cartridge_body.stl, cartridge_lid.stl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]
2024-08-04 Added Thermistormount for Chamber
    [V0.2_NTC_10k_B3950_Mount.stl]
2024-08-04 Adjusted thermistor mount
    [V0.2_NTC_10k_B3950_Mount.stl]
2024-08-04 Prepartion for chamber thermistor
    [printer.cfg]
2024-08-04 Adjusted thermistor mout
    [V0.2_NTC_10k_B3950_Mount.stl]
2024-08-04 Configure Neopixel
    [printer.cfg]
2024-08-06 Added waveshare-43-inch-display-mount-for-the-voron-v01-model_files
    [cover_front.stl, mount_front.stl, mount_left.stl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]
2024-08-07 Added printfiles for LED-brackets, bottom hinge and Cam mount
    [Brackets_1515_x2.stl, Front_Bottom_Right_Hinge_x1.stl, VoronV0_PiCam3_Mount_Angled_short_side.3mf]
2024-08-07 Removed first cam mount
    [VoronV0_PiCam3_Mount_Angled_short_side.3mf]
2024-08-07 Added better cam mount
    [Raspberry_Pi_Camera_Mount.step, Raspberry_Pi_Camera_Mount.stl]
2024-08-08 Added macro to control chamber led
    [printer.cfg]
2024-08-08 Better Names
    [printer.cfg]
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2024-08-09 Change invert on X & Y
    [printer.cfg]
2024-08-09 Adjust Z-Endstop-Position
    [printer.cfg]
2024-08-09 Added excluded_objects and adjusted run_current for X & Y
    [printer.cfg]
2024-08-09 Adjusted value
    [printer.cfg]
2024-08-09 Adjust wait-time before print start
    [printer.cfg]
2024-08-13 Adjusted position_endstop and max_temp
    [printer.cfg]
2024-08-13 Addjusted neopixel color
    [printer.cfg]
2024-08-13 Revert neopixel changes
    [printer.cfg]
2024-08-13 Renamed comment
    [printer.cfg]
2024-08-14 Added KAMP_Settings.cfg
    [KAMP_Settings.cfg]
2024-08-14 Enabled Line_Purge, Voron_Purge & Smart_Park
    [KAMP_Settings.cfg]
2024-08-15 Added better position after homing
    [printer.cfg]
2024-08-15 Added diffuser print files
    [voron v0 daylight diffuser v10.3mf, voron v0 daylight diffuser v10.stl]
2024-08-15 Changed chain_count for Neopixel
    [printer.cfg]
2024-08-15 Added print file for Front_Top_Right_Hinge
    [Front_Top_Right_Hinge_x1.stl]
2024-08-15 Added timelapse
    [printer.cfg]
2024-09-07 Added door hinges
    [Right_Bottom_Front_Hinge_x1.stl, Right_Top_Left_Hinge_x1.stl]
2024-09-08 Added print files for Endstops
    [1515 Endcap with Endstop Case v14.f3z, 1515 Endcap with Endstop Case v14.step, 1515 Endcap with Endstop Case v14.stl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]
2024-09-14 Update temperatur for extruder and extrude distance
    [printer.cfg]
2024-09-14 Added basefiles for 1515 end cap
    [1515 End Cap.step, 1515 End Cap.stl]
2024-09-14 Added printfiles for Dragon Burner v8
    [Bambu_Mount.stl, Brace_Straight.stl, Cowl_ZeroClick.stl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]
2024-09-14 Removed wait time and changed retract on print end
    [printer.cfg]
2024-09-15 Added print files for Dragon Burner v8 with Sherpa Mini
    [Bambu_Mount.stl, Brace_Straight.stl, Cowl_ZeroClick.stl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]
2024-10-22 Moved Config folder to new folder Config_SKR-Pico
    [1515_Hygrometer_mount.stl, Bambu_Mount.stl, Brace_Straight.stl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]
2024-10-22 Added printer.cfg for Manta M5P after MCU change
    [printer.cfg]
2024-10-22 Removed uart_adress
    [printer.cfg]
2024-10-26 Added fan configuration
    [printer.cfg]
2024-10-26 Fixed neopixel pin
    [printer.cfg]
2024-10-26 Additional fan config
    [printer.cfg]
2024-10-26 Fixed fan configuration
    [printer.cfg]
2024-10-26 Added endstop mount
    [1515 End Cap with Y Endstop for Voron V0.stl, x endstop.stl]
2024-10-26 Added thermistor mount
    [v0_chamber_thermistor_mount.stl]
2024-10-27 Added printfile for upper rear filament sensor
    [URBIFS-PC4.stl]
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2024-10-27 Adjustments for chamber thermistor
    [printer.cfg]
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2024-10-31 Fixed endstops
    [printer.cfg]
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2024-11-04 Fixed printersection
    [printer.cfg]
2024-11-05 Added temperature sensors for MCU & Host
    [printer.cfg]
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2024-11-05 Fixed extruder motor
    [printer.cfg]
2024-11-05 Added printfiles for foot and skirt
    [Rear_Skirt_x1.STL, [a]_Foot_Accent_A_x2.stl, [a]_Foot_Accent_B_x2.stl]
2024-11-06 Calibration and fixed stepper_z
    [printer.cfg]
2024-11-22 Added Toolheadreset in printer_start
    [printer.cfg]
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2025-02-01 Added new rear skirt with keystone jack
    [v0.2 Keystone Rear Skirt.stl]
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
